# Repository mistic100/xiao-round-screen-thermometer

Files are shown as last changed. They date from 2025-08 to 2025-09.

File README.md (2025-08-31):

# Home Assistant climate on Seeed Studio round screen

This a small project to display some data from Home Assistant on the 1.28 inches round display from Seeed Studio powered by a Xiao ESP32C3.

## Features

- 2 temperatures + humidity values
- 2 HVAC modes
- power draw
- automatically dim screen + touch to wake up
- automatically turn screen off when nobody is at home and during night (between 23h30 and 8h)

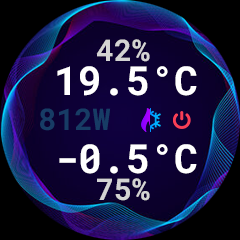
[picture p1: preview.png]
preview


## Configuration

### Home Assistant

Add a custom binary sensor with the following attributes:
- `time: "{{ states('sensor.time') }}"`
- `at_home: "{{ states('zone.home') | int(default=0) > 0 }}"`
- `power`: power draw + unit
- `temp_1` & `temp_2` temperature with max one decimal + unit
- `humi_1` & `humi_2` humidity with max one decimal + unit
- `mode_1` & `mode_2` one of `heat`, `cool`, `heat_cool` and `off`

**Example:**
```yaml
template:
  - binary_sensor:
    - unique_id: data_for_xiao
      state: true
      attributes:
        time: "{{ states('sensor.time') }}"
        at_home: "{{ states('zone.home') | int(default=0) > 0 }}"
        power: "{{ states('sensor.power_inst') }}W"
        temp_1: "{{ states('sensor.thermometre_sejour_temperature') | round(1, default=0) }}°C"
        temp_2: "{{ states('sensor.thermometre_exterieur_temperature') | round(1, default=0) }}°C"
        humi_1: "{{ states('sensor.thermometre_sejour_humidity') | round(0, default=0) }}%"
        humi_2: "{{ states('sensor.thermometre_exterieur_humidity') | round(0, default=0) }}%"
        mode_1: "{{ states('climate.ac_living_room') }}"
        mode_2: "{{ state_attr('climate.heater_bedroom', 'hvac_action') | replace('heating', 'heat') | replace('idle', 'off') }}"
```

### Firmware

Copy `secrets.tpl.h` into `secrets.h` and fill the values.

- `HA_TOKEN`: go to your HA profile page, then Security, and create a new Long lived token at the bottom of the page (keep the `Bearer ` prefix)
- `HA_URL`: fill in your HA hostname
- `HA_SENSOR`: set the id of the sensor created above
- `OTA_PASS`: choose a password to secure the Wifi OTA update

Copy `upload_params.tpl.ini` into `upload_params.ini` and fill the OTA password.

----

In `common.h` you can also configure:

- `WIFI_OTA`: comment to disable the Wifi OTA
- `TIME_START`, `TIME_END`: outside these hours the display turns off

## Compiling

Needs Visual Studio Code + PlatformIO.  
Run `Upload Filesystem Image` to pack and install the resources then `Upload and Monitor` to compile and install the firmware and check that everything is ok in the serial output.

## 3D printed case

A 3D printable desk case is provided. The screen is secured with a screwable ring.
It requires the usage of a small angled USB-C adapter ([Aliexpress](https://aliexpress.com/item/1005005966745930.html) or [Amazon](https://www.amazon.com/dp/B0B2NJ3P3L)).

The case itself is available in one piece, best for resin printer, or sliced for easier FDM printing (the two slices must be glued together).

 

[Also available on Printables](https://www.printables.com/model/1153601-desk-stand-for-seeed-studio-round-display)

## Links

Background image: https://stock.adobe.com/images/a/909375951

Generate VLW fonts: https://wiki.seeedstudio.com/Wio-Terminal-LCD-Anti-aliased-Fonts/

Pick RGB565 colors: https://rgbcolorpicker.com/565

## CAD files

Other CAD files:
model/_assembly.SLDASM
stl/case-full.stl
stl/ring.stl
model/case.SLDPRT
stl/case-split.stl
model/DS1021-1x7SF11.stp
model/Seeed Studio Round Display.SLDPRT
model/Seeed Studio XIAO-ESP32-C3.SLDPRT
model/Micro SD Card.SLDPRT
model/USB_C_90_Adapter_Type_C_Female_to_Male_Right_Angle_v3.step

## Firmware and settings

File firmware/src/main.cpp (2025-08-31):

#include <Arduino.h>
#include <WiFi.h>
#include <LittleFS.h>
#include "common.h"
#include "sensors.h"
#include "screen.h"

#ifdef WIFI_OTA
#include <ArduinoOTA.h>
#endif

#define TOUCH_INT D7

Data data;

void setup(void)
{
    Serial.begin(115200);

    if (!LittleFS.begin(false))
    {
        log_e("Failed to init LittleFS");
        return;
    }

    init_sensors();
    init_screen();

    pinMode(TOUCH_INT, INPUT_PULLUP);

    WiFi.mode(WIFI_STA);
    WiFi.begin(WIFI_SSID, WIFI_PASS);

    while (WiFi.status() != WL_CONNECTED)
    {
        display_error("WAIT WIFI");
        delay(500);
    }

#ifdef WIFI_OTA
    ArduinoOTA.setRebootOnSuccess(true);
    ArduinoOTA.setHostname(HOSTNAME);
    ArduinoOTA.setMdnsEnabled(true);
    ArduinoOTA.setPassword(OTA_PASS.c_str());
    ArduinoOTA.begin();
#endif

    draw_bg();

    log_i("Init done");
}

// From https://github.com/Seeed-Studio/Seeed_Arduino_RoundDisplay
bool chsc6x_is_pressed(void)
{
    if (digitalRead(TOUCH_INT) != LOW)
    {
        delay(1);
        if (digitalRead(TOUCH_INT) != LOW)
        {
            return false;
        }
    }
    return true;
}

void loop()
{
#ifdef WIFI_OTA
    ArduinoOTA.handle();
#endif

    if (update_sensors(data))
    {
        draw_screen(data);
    }

    update_brightness(is_always_on(data), chsc6x_is_pressed());
}

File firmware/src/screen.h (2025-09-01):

#include <SPI.h>
#include <TFT_eSPI.h>
#include "common.h"
#include "utils.h"

#define SCREEN_WIDTH 240
#define SCREEN_HEIGHT 240

#define ICON_W 32
#define SPRITE_X 40
#define SPRITE_Y 40
#define SPRITE_W 160
#define SPRITE_H 160

#define ANTIALIAS_COLOR 0x1006

TFT_eSPI tft = TFT_eSPI(SCREEN_WIDTH, SCREEN_HEIGHT);
TFT_eSprite spr = TFT_eSprite(&tft);

uint8_t brightness = 0;
uint32_t nextStartDim = 0;
uint32_t nextStepDim = 0;

PNG png;

static const char *TAG_BRIGHTNESS = "BRIGHT";
static const char *TAG_SCREEN = "SCREEN";

void set_brightness(uint8_t b)
{
    if (b != brightness)
    {
        analogWrite(TFT_BL, b * 2.55);
        brightness = b;
    }
}

void update_brightness(bool is_always_on, bool is_touch)
{
    uint32_t now = millis();

    if (is_touch)
    {
        // on touch: set 100% & start dim timer
        set_brightness(100);
        nextStartDim = now + DIM_TIMEOUT_MS;
        ESP_LOGI(TAG_BRIGHTNESS, "Restart");
    }
    else if (nextStartDim != 0)
    {
        // on dim timer end: start step timer
        if (nextStartDim < now)
        {
            nextStartDim = 0;
            nextStepDim = now;
            ESP_LOGI(TAG_BRIGHTNESS, "Start dim");
        }
    }
    else if (nextStepDim != 0)
    {
        // on step timer end
        if (nextStepDim < now)
        {
            // > min brightness: set -1 & restart step timer
            if (brightness > (is_always_on ? MIN_BRIGHTNESS : 0))
            {
                set_brightness(brightness - 1);
                nextStepDim = now + 20;
            }
            // stop step timer
            else
            {
                nextStepDim = 0;
                ESP_LOGI(TAG_BRIGHTNESS, "End dim");
            }
        }
    }
    else if (!is_always_on)
    {
        // if away: set 0%
        if (brightness > 0)
        {
            set_brightness(0);
            ESP_LOGI(TAG_BRIGHTNESS, "Off");
        }
    }
    else
    {
        // if at home: set min brightness
        if (brightness == 0)
        {
            set_brightness(MIN_BRIGHTNESS);
            ESP_LOGI(TAG_BRIGHTNESS, "On");
        }
    }
}

void display_error(const char *string)
{
    static bool isblinked = false;

    tft.setTextDatum(MC_DATUM);

    if (isblinked)
    {
        tft.setTextColor(TFT_RED, TFT_BLACK);
    }
    else
    {
        tft.setTextColor(TFT_BLACK, TFT_RED);
    }
    tft.drawString(string, tft.width() / 2, tft.height() / 2);

    isblinked = !isblinked;
}

void init_screen()
{
    tft.init();
    tft.setRotation(3);
    tft.fillScreen(TFT_BLACK);

    if (spr.createSprite(SPRITE_W, SPRITE_H) == nullptr)
    {
        log_e("cannot create sprite");
    }

    set_brightness(100);
    nextStartDim = millis() + DIM_TIMEOUT_MS;
}

void draw_bg()
{
    auto draw = [](PNGDRAW *pDraw)
    {
        uint16_t lineBuffer[SCREEN_WIDTH];
        png.getLineAsRGB565(pDraw, lineBuffer, PNG_RGB565_BIG_ENDIAN, 0xffffffff);
        tft.pushImage(0, 0 + pDraw->y, pDraw->iWidth, 1, lineBuffer);
    };

    png.open("/bg.png", pngOpen, pngClose, pngRead, pngSeek, draw);
    tft.startWrite();
    png.decode(NULL, 0);
    png.close();
    tft.endWrite();
}

void init_sprite()
{
    auto draw = [](PNGDRAW *pDraw)
    {
        if (pDraw->y >= SPRITE_Y && pDraw->y < SPRITE_Y + SPRITE_H)
        {
            uint16_t lineBuffer[SCREEN_WIDTH];
            png.getLineAsRGB565(pDraw, lineBuffer, PNG_RGB565_BIG_ENDIAN, 0xffffffff);
            spr.pushImage(-SPRITE_X, pDraw->y - SPRITE_Y, pDraw->iWidth, 1, lineBuffer);
        }
    };

    png.open("/bg.png", pngOpen, pngClose, pngRead, pngSeek, draw);
    png.decode(NULL, 0);
    png.close();
}

typedef struct
{
    uint8_t x, y;
} COORDS;

void draw_icon(const String &name, uint8_t x, uint8_t y)
{
    String path = "/" + name + ".png";
    COORDS coords = {x, y};

    auto draw = [](PNGDRAW *pDraw)
    {
        COORDS *coords = (COORDS *)pDraw->pUser;
        uint16_t lineBuffer[ICON_W];
        uint8_t maskBuffer[1 + ICON_W / 8];
        png.getLineAsRGB565(pDraw, lineBuffer, PNG_RGB565_BIG_ENDIAN, 0xffffffff);
        if (png.getAlphaMask(pDraw, maskBuffer, 255))
        {
            pushMaskedImageToSprite(&spr, coords->x - ICON_W / 2, coords->y + pDraw->y - ICON_W / 2, ICON_W, 1, lineBuffer, maskBuffer);
        }
    };

    png.open(path.c_str(), pngOpen, pngClose, pngRead, pngSeek, draw);
    png.decode((void *)&coords, 0);
    png.close();
}

void draw_screen(const Data &data)
{
    ESP_LOGI(TAG_SCREEN, "Start update");

    init_sprite();

    static const int xTemp = 200 - SPRITE_X;
    static const int yTemp1 = 68 - SPRITE_Y;
    static const int yTemp2 = 180 - SPRITE_Y;

    static const int xHumi = 150 - SPRITE_X;
    static const int yHumi1 = 40 - SPRITE_Y;
    static const int yHumi2 = 205 - SPRITE_Y;

    static const int xPower = 0;
    static const int yPower = SPRITE_H / 2.0 + 2;

    static const int xIcon = 165 - SPRITE_X;
    static const int yIcon = 120 - SPRITE_Y;

    spr.loadFont("RobotoMono-Bold-40", LittleFS);
    spr.setTextColor(TFT_WHITE, ANTIALIAS_COLOR);

    spr.setTextDatum(TR_DATUM);
    spr.drawString(data.temp1, xTemp, yTemp1);

    spr.setTextDatum(BR_DATUM);
    spr.drawString(data.temp2, xTemp, yTemp2);

    spr.loadFont("RobotoMono-Bold-30", LittleFS);
    spr.setTextColor(TFT_LIGHTGREY, ANTIALIAS_COLOR);

    spr.setTextDatum(TR_DATUM);
    spr.drawString(data.humi1, xHumi, yHumi1);

    spr.setTextDatum(BR_DATUM);
    spr.drawString(data.humi2, xHumi, yHumi2);

    spr.setTextColor(TFT_DARKCYAN, ANTIALIAS_COLOR);
    spr.setTextDatum(CL_DATUM);
    spr.drawString(data.power, xPower, yPower);

    spr.unloadFont();

    if (data.mode1 == "heat_cool" || data.mode1 == "heat" || data.mode1 == "cool" || data.mode1 == "off")
    {
        draw_icon(data.mode1, xIcon - 16, yIcon);
    }

    if (data.mode2 == "heat_cool" || data.mode2 == "heat" || data.mode2 == "cool" || data.mode2 == "off")
    {
        draw_icon(data.mode2, xIcon + 16, yIcon);
    }

    spr.pushSprite(SPRITE_X, SPRITE_Y);

    ESP_LOGI(TAG_SCREEN, "Screen updated");
}

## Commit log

2025-01-18 add stl
    [case-full.stl, case-split.stl, ring.stl]
2025-03-22 update model
    [_assembly.SLDASM, case.SLDPRT, ring.stl]
2025-06-15 Add power draw
